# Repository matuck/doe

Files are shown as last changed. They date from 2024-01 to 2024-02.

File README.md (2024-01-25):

# DOE 
Dactyl OLEDs Encoders(DOE)
This is a 5x6 dactyl keyboard that has oleds and encoders.  It uses the zmk firmware and nice!nano microcontrollers.
This repository will server as notes and a build log of the keyboard(s). As well as the firmware for it.

# Parts
Parts in this build see [MATERIALS.md](docs/MATERIALS.md)

# Resources
See [RESOURCES.md](docs/RESOURCES.md) for links to information I found helpful.

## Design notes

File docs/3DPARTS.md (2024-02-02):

# 3D Parts

The housing or shell of keyboard is 3D printed parts.  Dactyl keyboards can be generated in a number of ways.  I used the [Cosmos Beta](https://ryanis.cool/cosmos-beta) to generate mine.  I downloaded all the files initially including the step file.  The models would work as is but I wanted to add an external reset switch and a toggle switch for power.  So I took the step files, imported them into OnShape.  I then added the additional holes necessary.  Then exported to new stl files for the new models.

## Using the models

If you do not have a 3D printer, you can use a printing service.  In my case I printed my parts.  This is a time consuming process.  The main pieces take like half a day each to print.  After they are done printing there is quite a bit of post printing work to be done to them.  You have to remove the supports.  To do this I use a small pair of needle node pliers, my small cutters, and a hobby knife.  If you are using the amoeba king PCB's, I recommend to take one of them after the supports are cleared and making sure it sets in the keyboard shell.  You may have to do a little more clenaing up of the shell.  The PCB's will fit snuggly into place.

## Preping the case 

Test fit your pieces.  Make sure your OLED's fit where they are suppose to.  Also make sure your encoders fit.  In my case I had to make the encoder shaft hole a touch larger.  I also had to trim some of the area that holds the encoder to get it to sit all the way in.

### Insert your M3 thread inserts

Heat your soldering iron 50 to 100 degress hotter than what you printed your case pieces at.  I recommed to have a cone tip point for this.  Take one of your inserts and and set it into place give it a light push so that it sticks In place.  Now take your soldering iron and put the tip inside the insert letting it heat up.  Genetly and slowly push the insert in until it is flush with the rest of the plastic.  The slower the plastic heats and cools around the insert the strong the bond will be.  Repeat this process till all of your inserts are in

That is it for the case prep.

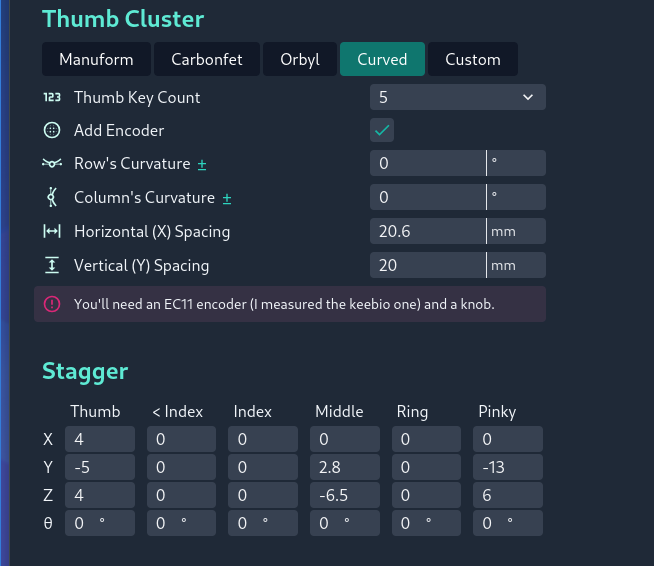
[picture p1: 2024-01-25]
assets/config_screenshots/Screenshot from 2023-11-13 10-11-27.png

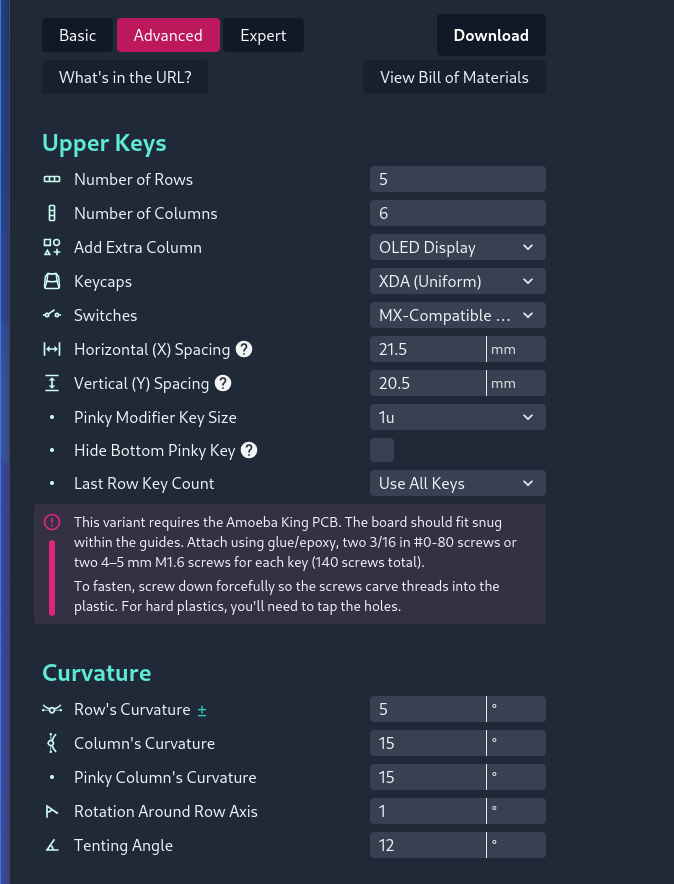
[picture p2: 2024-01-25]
assets/config_screenshots/Screenshot from 2023-11-13 10-10-57.png

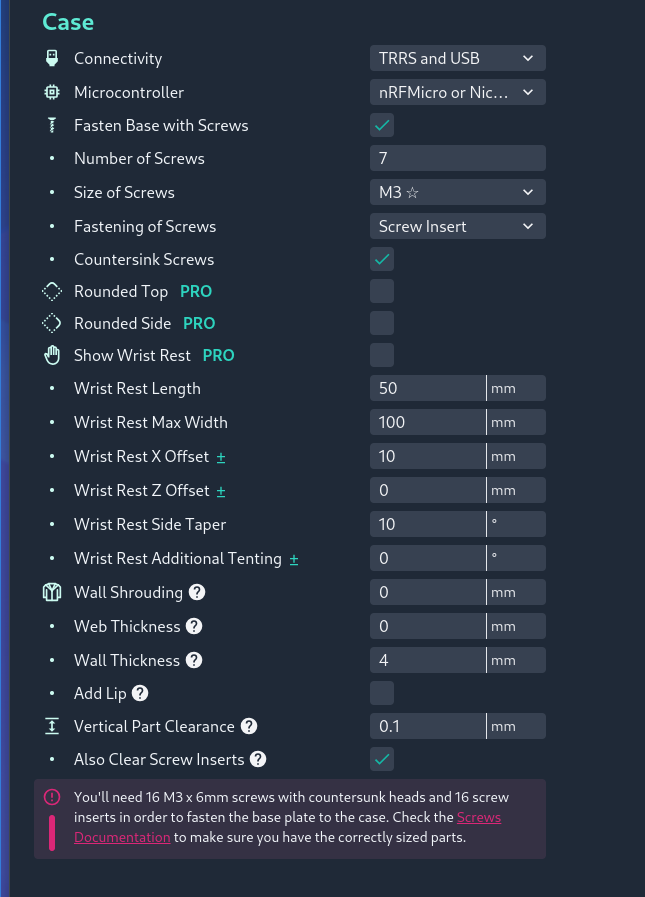
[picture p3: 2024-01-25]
assets/config_screenshots/Screenshot from 2023-11-13 10-11-57.png

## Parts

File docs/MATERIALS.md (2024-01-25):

- [ ] [64 DSA Keycaps 1u](https://a.co/d/5FVZjlk)
- [ ] [2 EC11 Encoders](https://a.co/d/7Llmvvl)
- [ ] [64 MX Switches](https://a.co/d/f4Ez9as)
- [ ] [2 128x32 1" OLED Displays](https://a.co/d/jakgzZB)
- [ ] 64 Amobea King PCB - You can purchase from a supplier like diykeyboards.com, or I downloaded the gerbers from [repo](https://github.com/JKing-B16/keyboard-pcbs) and used a pcb maker like jlcpcb
- [ ] [64 Kailh Hotswap Sockets](https://a.co/d/hmojMy0)
- [ ] [64 SK6812MINI-E LEDs (optional)](https://a.co/d/bHo7S5S)
- [ ] [64 1n4148 Diodes (SOD-123)](https://a.co/d/7UF2qdy)
- [ ] [2 Nice!Nano](https://typeractive.xyz/products/nice-nano)I have to go to the nice!nano site and look for suppliers sometimes because they are frequently sold out.
- [ ] [2 PJ-320A TRRS](https://a.co/d/5E0rH3P)
- [ ] 1 Spool Margnet wire or [28 guage wire insulated](https://a.co/d/cO7KOOr)
- [ ] [18 M3x6 mm flat head screws](https://a.co/d/0dWPl0C)
- [ ] 2 M3x 10 mm flat head screws -see above
- [ ] [20 M3 Screw Inserts](https://a.co/d/1BAoGnt)
- [ ] [8 rubber/silicon feet](https://a.co/d/4mPpy1K)
- [ ] [Rocker switch](https://a.co/d/7DjVT1c)
- [ ] [momentary switch](https://a.co/d/ejbfsuv)
- [ ] [chip sockets](https://a.co/d/53iLW04)
- [ ] [JST connectors](https://a.co/d/fDnPNci)
- [ ] [2000 mAh Lipo battery](https://a.co/d/ciyPf8c)
- [ ] [Solder](https://a.co/d/9iWVFa4)
- [ ] [Rosin Flux](https://a.co/d/f6ZY7V4)
- [ ] [Solder wick](https://a.co/d/9JIPu0U)
- [ ] [Round pin headers](https://a.co/d/fynia84)
- [ ] 3d printed parts (the models I used are in the models folder, or you can go to [Cosmos beta](https://ryanis.cool/cosmos/beta) and generate your own.)

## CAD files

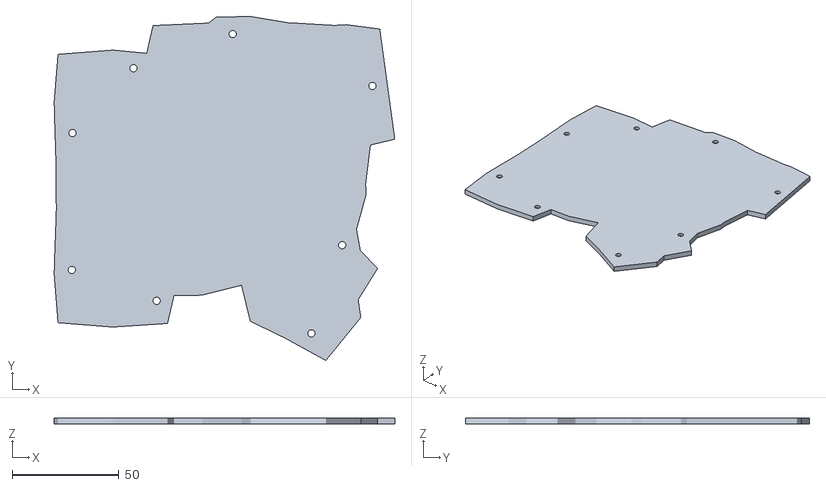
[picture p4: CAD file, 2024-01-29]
models/plate-left.stl
159.3 x 160.9 x 3.00

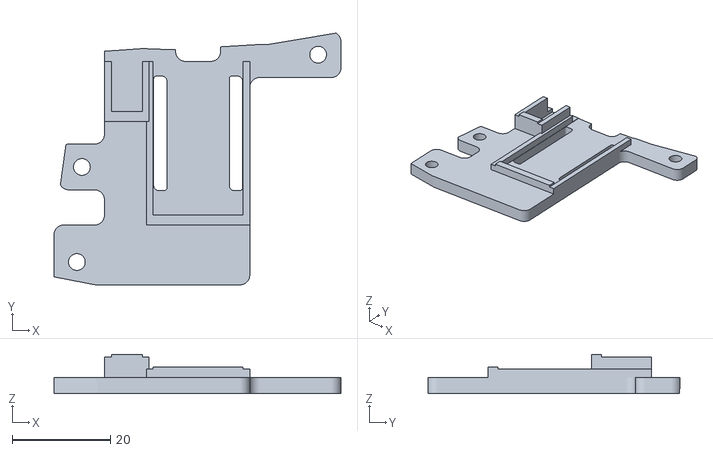
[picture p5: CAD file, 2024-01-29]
models/holder-right.stl
58.4 x 51.2 x 8.00

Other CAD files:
models/plate-right.stl
models/holder-left.stl

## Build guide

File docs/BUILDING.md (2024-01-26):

# Prep work

## Encoders (optional)

I personally want my endoders to run more smoothly.  This is an optional step but will make the encoders easy to turn.  I modify my encoders to remove the detents.  This is relatively simple.  This is the [video](https://www.youtube.com/watch?v=YYPsISzesLs) I followed to modify my encoders.  You can skip to 3:30 of the video, before that it is desoldering an encoder from a board.

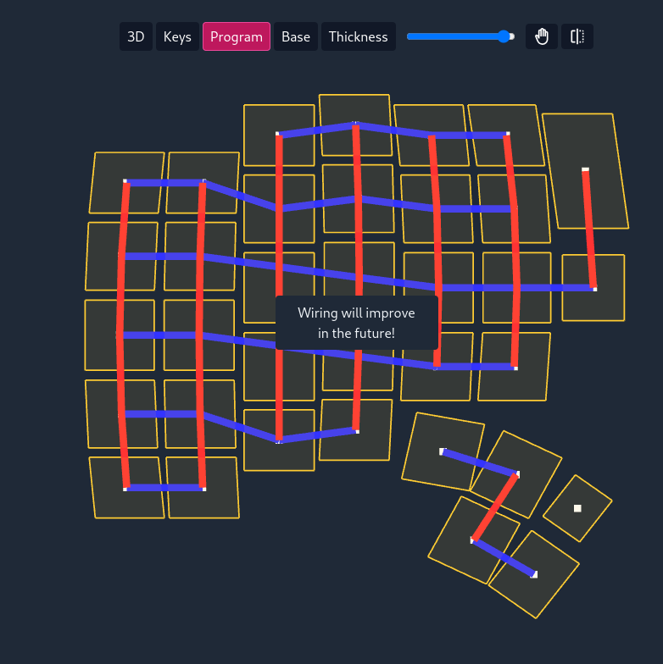
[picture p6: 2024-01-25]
assets/wiring_screenshot.png

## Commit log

2024-01-25 add led pins
2024-01-25 Rename config/boards/shields/doe/nice_nano_v2.overlay to config/boards/shields/doe/boards/nice_nano_v2.overlay
    Put in right place
2024-01-27 update models for oleds [skip actions]
    [holder-left.stl, holder-right.stl, plate-left.stl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]
2024-01-29 update models with some extra holes for switches
    [holder-left.stl, holder-right.stl, plate-left.stl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]
2024-02-20 add encoder support
2024-02-20 enable encoder
2024-02-20 add leds
